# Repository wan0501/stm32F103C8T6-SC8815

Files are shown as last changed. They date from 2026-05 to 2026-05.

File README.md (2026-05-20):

# STM32F103C8T6 + SC8815 双向 BUCK-BOOST 开关电源

本项目基于 **STM32F103C8T6** 微控制器和 **Silergy SC8815** 双向升降压控制器，设计了一款**可调双向 Buck-Boost 开关电源**，支持升压、降压以及双向功率传输。

---

## 目录

- [项目概述](#项目概述)
- [技术规格](#技术规格)
- [文件说明](#文件说明)
- [系统架构](#系统架构)
- [硬件设计](#硬件设计)
- [软件设计](#软件设计)
- [使用说明](#使用说明)
- [许可证](#许可证)

---

## 项目概述

SC8815 是一款高效率、宽电压范围的同步升降压（Buck-Boost）控制器，支持 I²C 数字接口控制。本项目以 **STM32F103C8T6** 作为主控 MCU，通过 I²C 总线配置 SC8815 的工作模式，实现：

- **双向功率传输**：支持正向（降压输出）和反向（升压回充）两种工作模式
- **可调输出电压 / 电流**：通过按键 / 编码器 / 串口指令实时调节
- **信息显示**：OLED / LCD 屏幕实时显示电压、电流、功率等参数
- **闭环控制**：MCU 采集输出反馈，动态调整 SC8815 参数

### 应用场景

- 可调实验室电源
- 电池充电 / 放电管理
- USB PD 可调电源
- 便携式设备供电
- 太阳能 MPPT 前端

---

## 技术规格

| 参数 | 条件 | 数值 | 单位 |
|---|---|---|---|
| **输入电压** | — | 5 ~ 36 | VDC |
| **输出电压** | 可调 | 0 ~ 36 | VDC |
| **输出电流** | 可调 | 0 ~ 5（取决于散热） | A |
| **开关频率** | SC8815 设定 | 200 ~ 600（可调） | kHz |
| **拓扑结构** | — | 四开关同步 Buck-Boost | — |
| **控制方式** | — | I²C 数字控制（SC8815） | — |
| **MCU** | — | STM32F103C8T6 | — |
| **通信接口** | MCU | I²C, UART（串口指令） | — |
| **保护功能** | — | 过流 / 过温 / 短路 | — |

---

## 文件说明

| 文件 | 说明 |
|---|---|
| `SC8815.SchDoc` | **Altium Designer 原理图源文件**，包含完整的电路设计 |
| `SC8815原理图+PCB.pdf` | **原理图 + PCB 设计 PDF**，方便直接查看 |
| `SC8815.pdf` | **SC8815 数据手册或参考设计文档** |

---

## 系统架构

### 硬件框图

```
                       ┌─────────────────┐
                       │  5 ~ 32V 输入    │
                       └────────┬────────┘
                                │
                     ┌──────────▼──────────┐
                     │  输入滤波 & 保护      │
                     │  (保险丝 / 防反接)    │
                     └──────────┬──────────┘
                                │
                     ┌──────────▼──────────┐
                     │                     │
                     │   SC8815            │
                     │   四开关 Buck-Boost  │
                     │   同步整流            │
                     │                     │
                     └──────────┬──────────┘
                                │
                     ┌──────────▼──────────┐
                     │  输出滤波 & 检测      │
                     │  (电压 / 电流采样)    │
                     └──────────┬──────────┘
                                │
                       ┌────────▼────────┐
                       │  0 ~ 32V 输出    │
                       └─────────────────┘

  ┌─────────────────────────────────────────────────┐
  │                STM32F103C8T6                    │
  │  ┌──────────┐  ┌──────────┐  ┌──────────────┐  │
  │  │  I²C     │  │  ADC     │  │  UART / OLED  │  │
  │  │ ←→SC8815│  │ 采样反馈  │  │ 显示 / 通信   │  │
  │  └──────────┘  └──────────┘  └──────────────┘  │
  └─────────────────────────────────────────────────┘
```

### SC8815 简介

SC8815 是 Silergy（现 Renesas）推出的同步升降压控制器，主要特性：

- **四开关 Buck-Boost 拓扑**： seamless 模式切换，无盲区
- **宽输入 / 输出电压范围**：2.7V ~ 36V
- **I²C 可编程**：调节输出电压、电流限制、开关频率等
- **高效率**：同步整流，峰值效率 > 95%
- **双向工作**：支持正向和反向电流
- **内置保护**：OCP、OVP、OTP、UVLO

### STM32F103C8T6 功能

- **I²C 主机**：配置 SC8815 寄存器，设定工作参数
- **ADC 采样**：采集输出电压、电流、温度等模拟量
- **显示驱动**：驱动 OLED / LCD 显示实时数据
- **用户输入**：按键 / 编码器调节电压和电流
- **通信接口**：UART 串口命令控制

---

## 硬件设计

### 功率级 — SC8815 外围

- **功率 MOSFET**：四颗 N-MOSFET 构成 H 桥 Buck-Boost
- **功率电感**：根据开关频率和电流选择合适感值
- **输入 / 输出电容**：低 ESR 陶瓷电容 + 电解电容
- **电流检测**：低阻值采样电阻 + 差分运放
- **自举电路**：上管驱动自举供电

### 控制级 — STM32 外围

- **I²C 上拉**：SC8815 的 SCL / SDA 上拉电阻
- **分压采样**：输出电压分压电阻网络连接 MCU ADC
- **电流采样**：芯片自带12位数ADC采样
- **显示接口**：I²C OLED（SSD1306）
- **用户输入**：按键

### PCB 布局要点

- **功率回路**：电流环路尽可能小，减少寄生电感和 EMI
- **大电流走线**：加宽敷铜或开窗加锡
- **散热**：MOSFET 底部过孔散热，功率器件布局分散
- **模拟 / 数字分区**：SC8815 模拟信号远离数字噪声
- **采样走线**：Kelvin 连接方式，避免共阻抗干扰

---

## 软件设计

### 主循环流程

```
系统初始化 → SC8815 I²C 初始化 → 参数配置
     │
     ├─ 循环：
     │   ├─ 读取 SC8815 状态寄存器
     │   ├─ ADC 采集输出电压 / 电流
     │   ├─ 处理用户输入（按键 / 编码器）
     │   ├─ 更新 SC8815 输出设定
     │   ├─ 刷新 OLED 显示
     │   └─ 处理串口命令（可选）
     │
     └─ 保护检测（过流 / 过温）
```

### I²C 寄存器配置

- **输出电压设定**：通过 I²C 写入 VOUT 寄存器
- **电流限制设定**：通过 I²C 写入 ILIM 寄存器
- **工作模式选择**：强制 DCM / CCM / 自动切换
- **状态读取**：读取故障状态、输入 / 输出电压等

### 通信协议（可选）

可通过 UART 串口发送指令控制电源：

| 命令 | 功能 |
|---|---|
| `SETV x.x` | 设置输出电压 |
| `SETI x.x` | 设置电流限制 |
| `GET` | 读取当前电压 / 电流 |
| `ON / OFF` | 输出使能 / 关闭 |

---

## 使用说明

### 硬件组装

1. 参照 `SC8815.SchDoc` 原理图焊接元器件
2. 确保功率 MOSFET 和电感选型正确
3. 检查极性：输入防反接保护
4. 初次上电建议串入限流电阻 / 电子负载

### 固件烧录

- 使用 **Keil MDK** 或 **STM32CubeIDE** 编译
- 通过 **ST-Link** 或 **UART ISP** 烧录至 STM32F103C8T6

### 操作方式

- **按键调压**：UP / DOWN 按键调整输出电压

### 注意事项

- 输入电压不要超过 SC8815 和 MOSFET 的耐压上限
- 大电流输出时注意散热，必要时加装散热片或风扇
- 严禁输出短路（依赖保护电路，但仍需避免）

---

## 许可证

本项目基于 MIT 许可证开源 — 详见 [LICENSE](LICENSE) 文件。

---

## 免责声明

本项目为开源设计参考，**不构成产品级设计保证**。使用者应自行验证电路参数是否满足自身应用需求。因使用本设计造成的任何损失，作者不承担责任。

---

**作者**: [wan0501](https://github.com/wan0501)
有需要代码的联系我微信：wxy2836810209
**如果这个项目对你有帮助，欢迎 Star ⭐ 和 Fork！**

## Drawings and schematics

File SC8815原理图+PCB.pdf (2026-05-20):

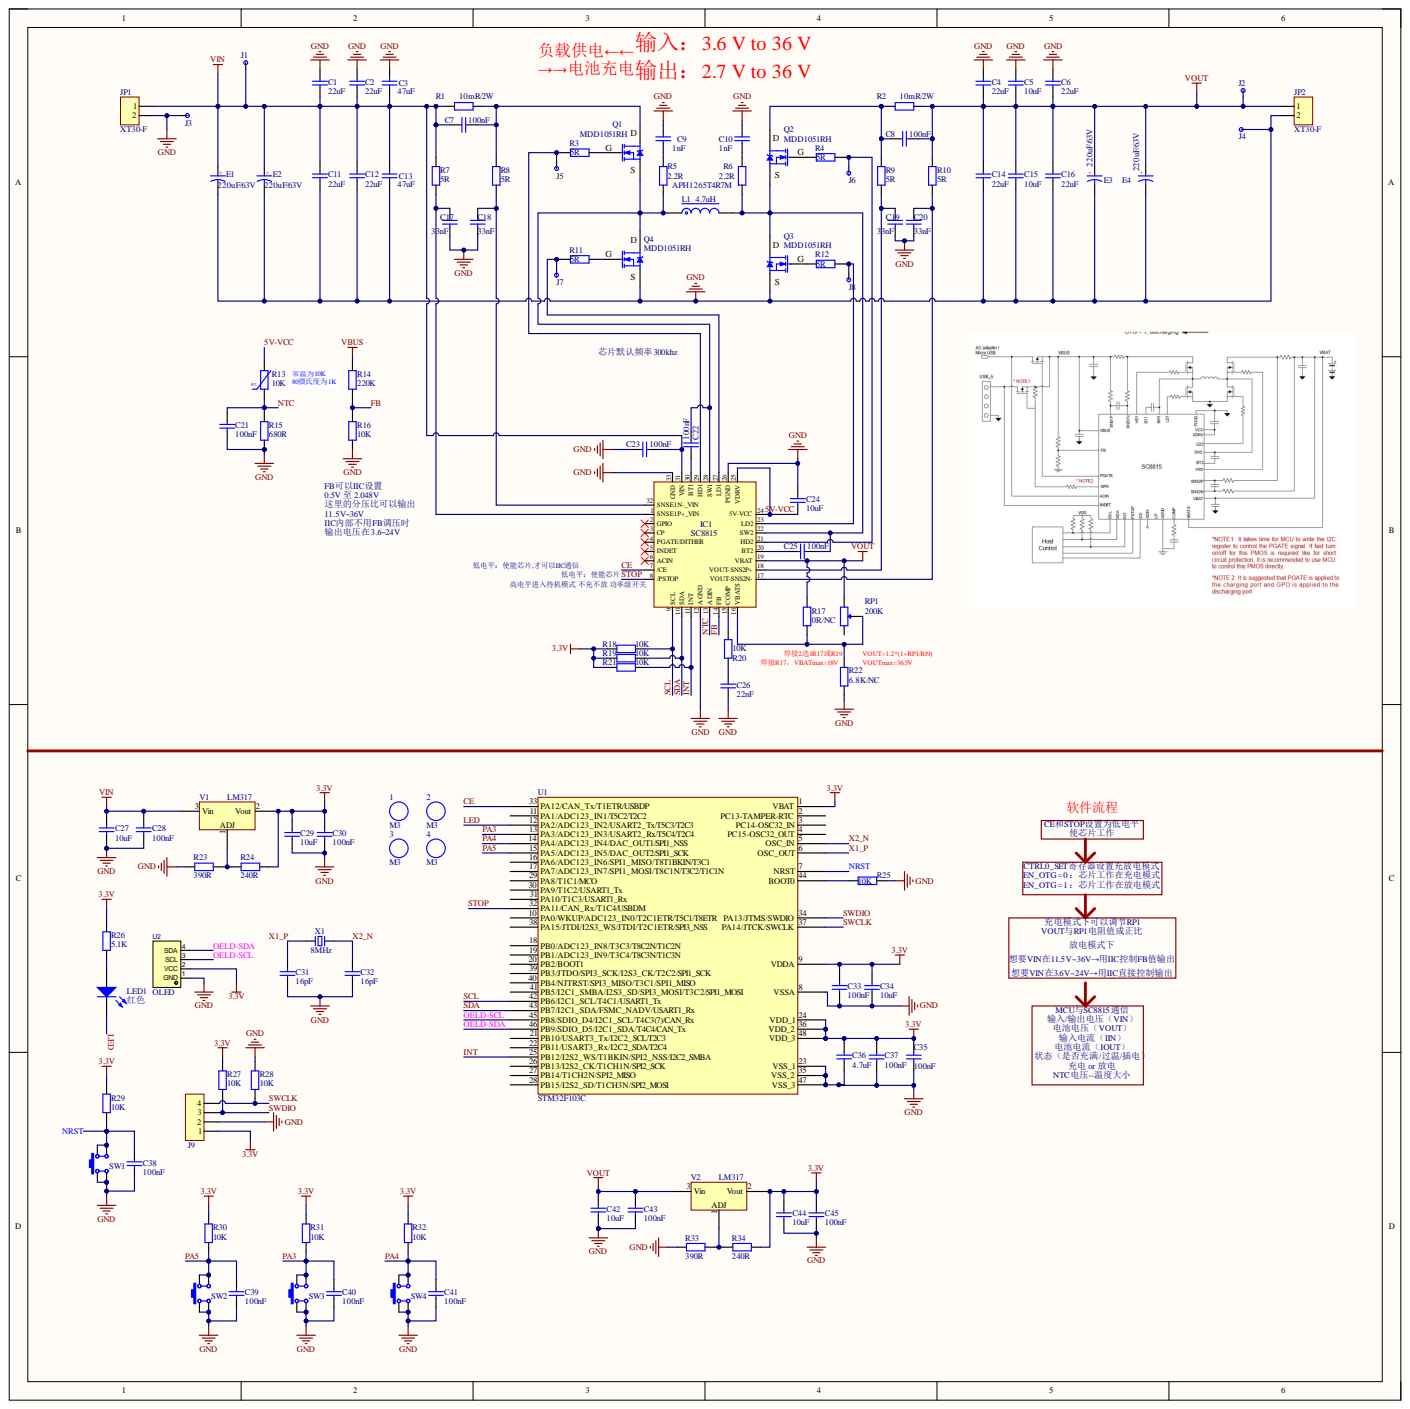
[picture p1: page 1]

5V-VCC | | 芯片默认频率300khz | GND C24 10uF

MCU与SC8815通信
输入/输出电压（VIN） 电池电压（VOUT）

输入电流（IIN） 电池电流（IOUT）

状态（是否充满/过温/插电）

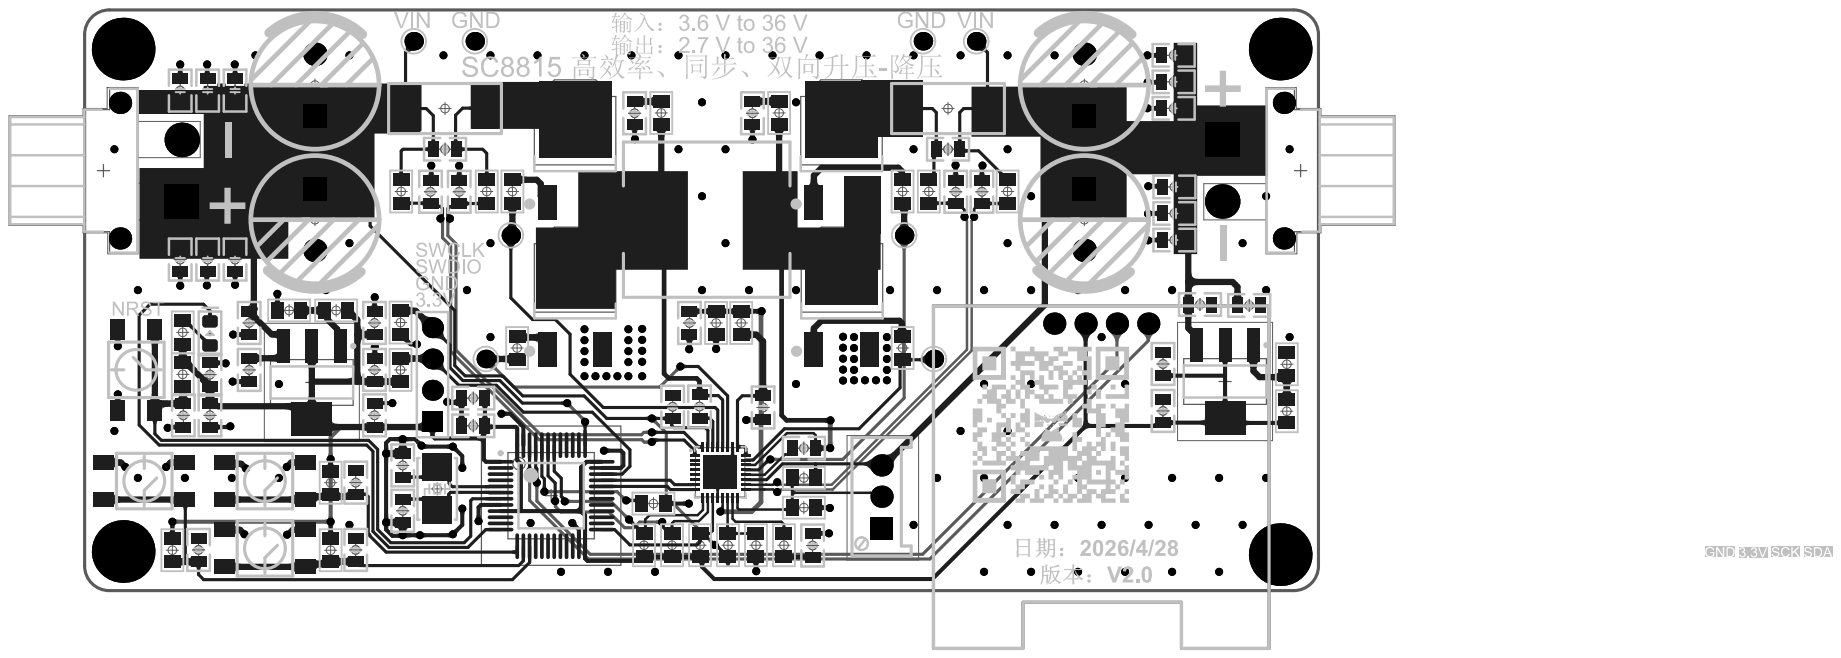
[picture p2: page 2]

Comment | Description | Designator | Footprint | LibRef | Quantity
M3 | 铜柱孔 | 1, 2, 3, 4 | M3 125X200 | M3 | 4
22uF | 贴片电容/MLCC电容 | C1, C2, C4, C6, C11, C12, C14, C16 | C0805_L | C | 8
47uF | 贴片电容/MLCC电容 | C3, C13 | C0805_L | C | 2
10uF | 贴片电容/MLCC电容 | C5, C15, C24, C27, C29, C34, C42, C44 | C0805_L | C | 8
100nF | 贴片电容/MLCC电容 | C7, C8, C21, C22, C23, C25, C28, C30, C33, C35, C37, C38, C39, C40, C41, C43, C45 | C0805_L | C | 17
1nF | 贴片电容/MLCC电容 | C9, C10 | C0805_L | C | 2
33nF | 贴片电容/MLCC电容 | C17, C18, C19, C20 | C0805_L | C | 4
22nF | 贴片电容/MLCC电容 | C26 | C0805_L | C | 1
16pF | 贴片电容/MLCC电容 | C31, C32 | C0805_L | C | 2
4.7uF | 贴片电容/MLCC电容 | C36 | C0805_L | C | 1
220uF/63V | 直插固态电容 | E1, E2, E3, E4 | CT 5.0*10*13 - R | CS | 4
SC8815 | 双向同步升降压IC | IC1 | QFN32_L4.0-W4.0-P0.4 | SC8815 | 1
CHECK | 测试点 | J1, J2, J3, J4, J5, J6, J7, J8 | CHECK-A | CHECK | 8
HDR-1X4 | 4P接插件 | J9 | HDR2.54-LI-4P | Header 4 | 1
XT30-F | XT30母座 | JP1, JP2 | XT30PW-F | XT30-F | 2
4.7uH | 一体成型电感 | L1 | SMD,13.5x12.6mm | L-Molding Choke | 1
红色 | 贴片LED | LED1 | LED0805_G | LED | 1
MDD1051RH | N沟道 30V/80A | Q1, Q2, Q3, Q4 | TO252 | NCE3080 | 4
10mR/2W | 贴片电阻 | R1, R2 | R2512_M | R | 2
5R | 贴片电阻 | R3, R4, R7, R8, R9, R10, R11, R12 | R0805_L | R | 8
2.2R | 贴片电阻 | R5, R6 | R0805_L | R | 2
10K | 热敏电阻 | R13 | R0805-HP_L | RT | 1
220K | 贴片电阻 | R14 | R0805_L | R | 1
680R | 贴片电阻 | R15 | R0805_L | R | 1
10K | 贴片电阻 | R16, R18, R19, R20, R21, R25, R27, R28, R29, R30, R31, R32 | R0805_L | R | 12
0R/NC | 贴片电阻 | R17 | R0805_L | R | 1
6.8K/NC | 贴片电阻 | R22 | R0805_L | R | 1
390R | 贴片电阻 | R23, R33 | R0805_L | R | 2
240R | 贴片电阻 | R24, R34 | R0805_L | R | 2
5.1K | 贴片电阻 | R26 | R0805_L | R | 1
200K | 单联电位器 | RP1 | 3296W | RP | 1
4.5x4.5x3.8 | 贴片4.5x4.5轻触开关 | SW1, SW2, SW3, SW4 SW SMD-4.5*4.5*3.8 | | SW SMD-4.5x4.5 | 4
STM32F103C | STM32单片机48引脚 | U1 | LQFP-48_M | STM32F103C | 1
OLED | 0.96OLED | U2 | OLED | OLED | 1
LM317 | 可调线性稳压芯片 | V1, V2 | SOT223_M | LM317 | 2
8MHz | 2脚无源晶振(谐振 器） | X1 | XTAL-5032-2P | XTAL-2P | 1
